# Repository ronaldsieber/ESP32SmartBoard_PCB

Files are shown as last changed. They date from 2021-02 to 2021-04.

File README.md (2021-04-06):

# ESP32SmartBoard_PCB
**KiCad project of a Printed Cuircit Board (PCB) for ESP32 with Temperature/Humidity/CO2 Sensors, User LEDs and Buttons.**

In the past I've implemented various Smart Projects with the ESP32 on break-out boards. On the one hand, break-out boards are very useful because they make hardware modifications as easy as software changes. On the other hand, it is very cumbersome to build several copies of the same circuit with break-out boards. Furthermore, they are mechanically fragile and not really particularly visually appealing. Therefore they are not very suitable for permanent use in the visible area of living rooms.

For this reason I designed the **ESP32SmartBoard_PCB**, which combines different projects on a single, professionally producible PCB. This allows now for reproducing multiple copies of a device without great effort and hide them in a small housing if necessary.

## Board Features

The *ESP32SmartBoard_PCB* contains the following components:
- ESP32 Development Kit
- DHT22 (combined temperature and humidity sensor)
- MH-Z19 (CO2 sensor with integrated temperature sensor)
- 9 freely usable user LEDs (LED0..LED8, arranged in one row and usable as a LED Bar)
- 3 freely usable user Buttons (KEY0, KEY1, BLE_CFG)

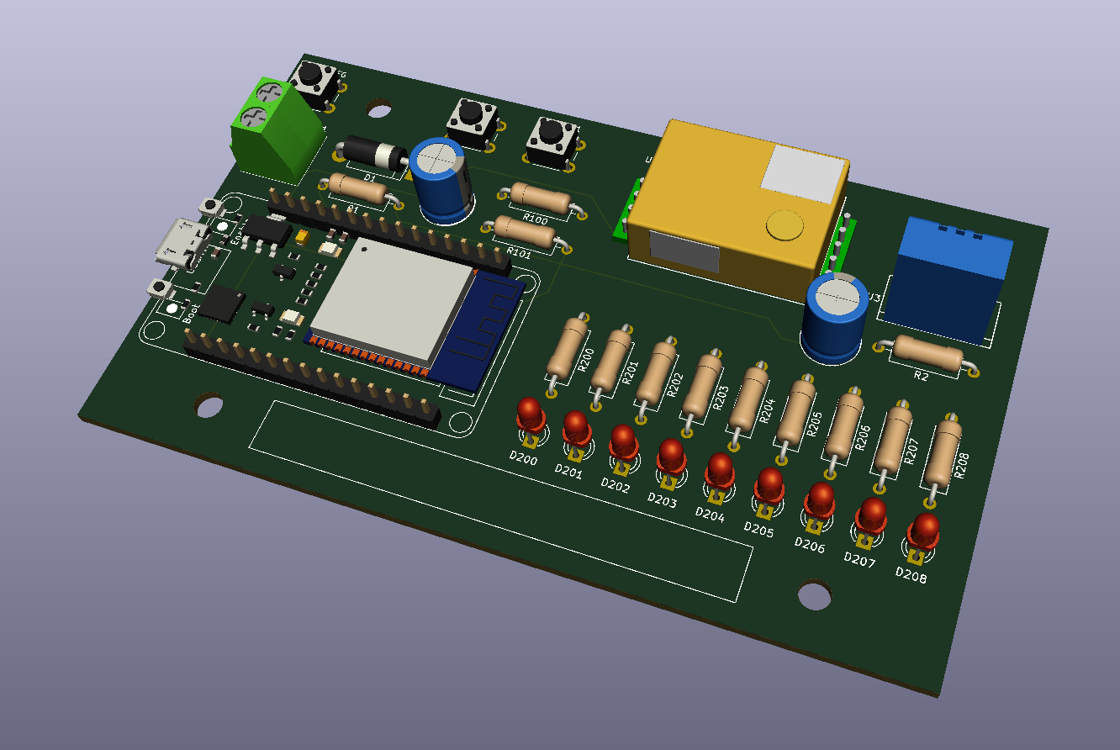
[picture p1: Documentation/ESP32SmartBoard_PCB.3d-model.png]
\[kicad_3d_model\]


## Board Description

The *ESP32SmartBoard_PCB* is a two-layer Printed Circuit Board (PCB), assembled on one side and only uses THT components (Through Hole Technology) that are very easy to solder. It can therefore be used very easily also by students and hobbyists.

The values of all components are specified in the [Schematic](Documentation/ESP32SmartBoard_PCB.sch.pdf).

The PCB size and the positions of the mounting holes allow installation in the plastic universal housing of 135 x 95 x 45 mm (article number 523117). This polystyrene housing (EPS) can be easily processed mechanically (e.g. cut out a viewing window for the LED Bar). It is available from various providers on the Internet.

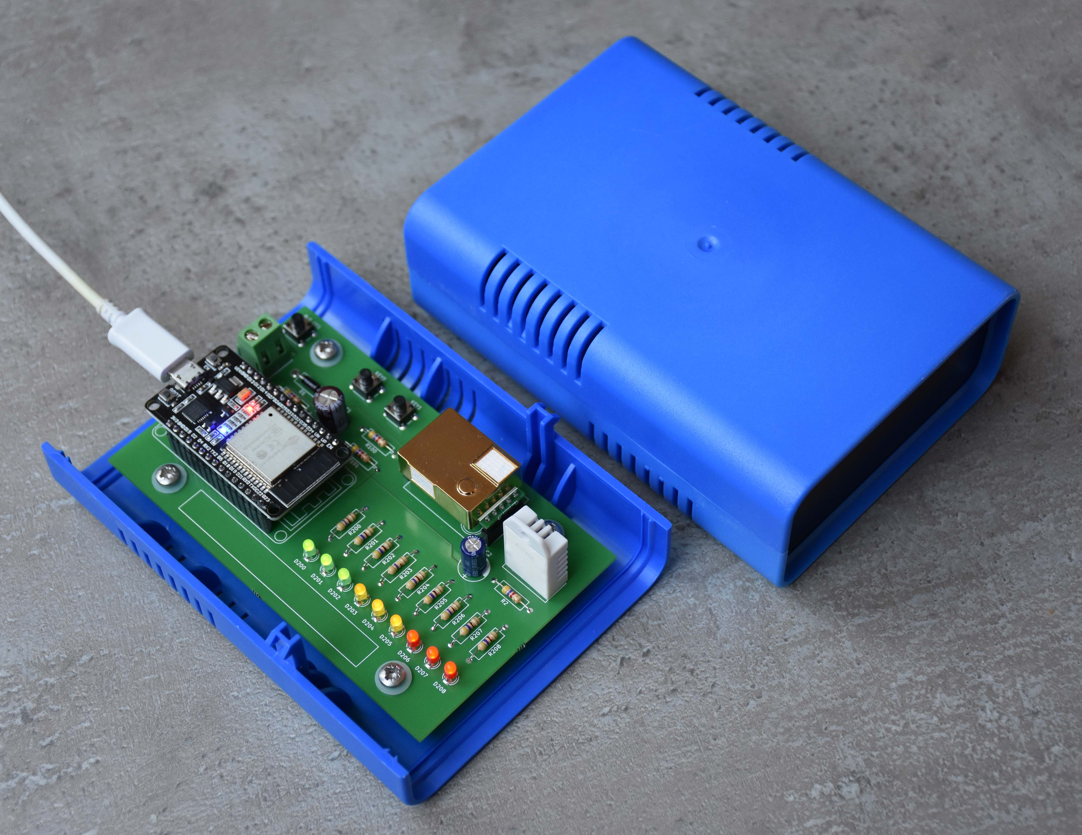
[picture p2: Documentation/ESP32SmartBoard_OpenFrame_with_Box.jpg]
\[ESP32SmartBoard_OpenFrame_with_Box\]


By searching in the Internet, several PCB manufacturers can be found who are able to directly import the KiCad layout file [ESP32SmartBoard_PCB.kicad_pcb](ESP32SmartBoard_PCB/ESP32SmartBoard_PCB.kicad_pcb). The PCBs with silkscreen (assembly printing) on the top are then sent by post after a few days.

## Power Supply

There are following options for the power supply of the board:
- Via USB connection of the ESP32 Development Kit (in this case Pin15/Vin of the ESP32DevKit acts as an output and supplies the rest of the circuit)
- Supply of 5 ... 6VDC to connector J1 (in this case the rest of the board supplies the ESP32DevKit and Pin15/Vin acts as an input)

## Commissioning

With the Arduino sketch from the [ESP32SmartBoard_IoCheck](https://github.com/ronaldsieber/ESP32SmartBoard_IoCheck) repository, all components of the board can be checked for correct function after assembly. The sketch is also a good starting point for new software projects based on this board.

## Schematic Symbols, Footprints and 3D Models

Not all schematic symbols, footprints and 3D models required for *ESP32SmartBoard_PCB* are contained in the native installed KiCad library. [External_KiCad_Parts.txt](Documentation/External_KiCad_Parts.txt) lists the additional components and their download links.

## Practice Notes

- The user LEDs are arranged in one row and can be used as a LED Bar. The colors of the LEDs should be selected according to the respective application. For example, to show the CO2 level in the form of a scale, the following grouping is suitable:
  * LED0..LED2: green = excellent
  * LED3..LED5: yellow = acceptable
  * LED6..LED8: red = critical

- It seems that there are several versions of the ESP32 Development Kit and the MH-Z19 CO2 sensor with pins of different widths. In my components, the diameter of the connection pins are larger than the diameter of the soldering pads in the footprint. This prevented me from soldering the components directly onto the board. However, I was able to solve the problem by using Pin Headers (see image above). The solder connections of the Pin Headers are small enough for the solder pads and the ESP32 Development Kit and MH-Z19 CO2 sensor can be easily plugged in.

## Software Projects for the ESP32SmartBoard

 - [ESP32SmartBoard_IoCheck](https://github.com/ronaldsieber/ESP32SmartBoard_IoCheck) - Checking of all components during commissioning and starting point for new software projects based on this board.
   
 - [ESP32SmartBoard_HttpSensors](https://github.com/ronaldsieber/ESP32SmartBoard_HttpSensors) - Embedded WebServer based Arduino Sketch for ESP32SmartBoard
   
 - [ESP32SmartBoard_MqttSensors](https://github.com/ronaldsieber/ESP32SmartBoard_MqttSensors) - MQTT Client based Arduino Sketch for ESP32SmartBoard

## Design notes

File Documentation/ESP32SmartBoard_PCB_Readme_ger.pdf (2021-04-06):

## ESP32SmartBoard_PCB

KiCad Projekt eines Printed Cuircit Boards (PCB) für ESP32 mit Temperatur-, Luftfeuchtigkeits- und CO2-Sensor, User LEDs und Bottons.

In der Vergangenheit habe ich verschiedene Smart Projects mit dem ESP32 auf Break-out Boards realisiert. Auf der einen Seite sind Break-out Boards sehr nützlich, da sie Hardware Modifikationen genauso einfach machen wie Software Änderungen. Auf der anderen Seite ist es aber sehr umständlich, mehrere Exemplare derselben Schaltung mit Break-out Boards aufzubauen. Außerdem sind diese mechanisch fragil und optisch nicht besonders ansprechend. Deswegen sind sie für eine Dauereinsatz im Sichtbereich von Wohnräumen nicht besonders geeignet.

Aus diesem Grund habe ich das ESP32SmartBoard_PCB designet, mit dem sich verschiedene Projekte auf einer einzigen, professionell produzierbaren PCB zusammenfassen lassen. Damit kann ich nun mehrfache Exemplare eines Gerätes ohne großen Aufwand reproduzieren und bei Bedarf in einem kleinen Gehäuse verstecken.

Board Features

Das ESP32SmartBoard_PCB beinhalte folgende Komponenten:
- ESP32 Development Kit
- DHT22 (kombinierter Temperatur- und Luftfeuchte-Sensor)
- MH-Z19 (CO2 Sensor mit integriertem Temperatur Sensor)
- 9 frei verwendbare User LEDs (LED0..LED8, in einer Reihe angeordnet und als Led Bar nutzbar)
- 3 frei verwendbare User Buttons (KEY0, KEY1, BLE_CFG)

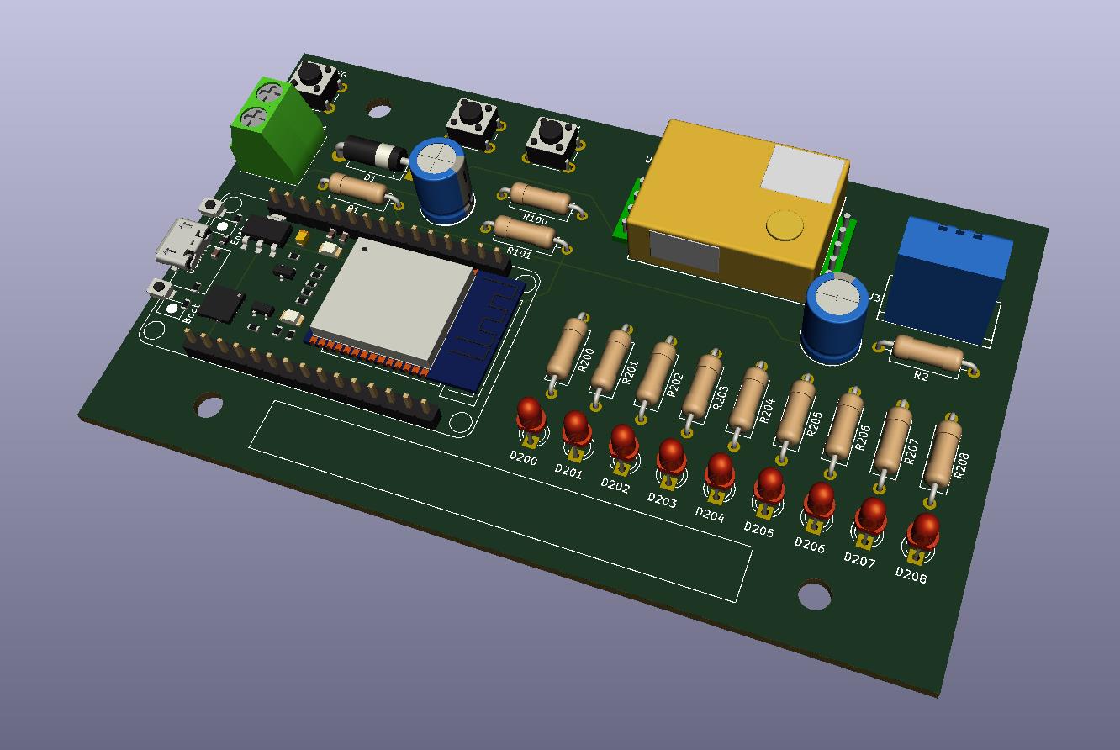
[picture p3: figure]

[kicad_3d_model]

Board Beschreibung

Das ESP32SmartBoard_PCB ist eine zweilagige Leiterplatte, einseitig bestückt und verwendet nur sehr einfach zu lötende THT Bauteile (Through Hole Technology). Es kann somit sehr leicht auch von Schülern und Bastlern genutzt werden.

Die Werte aller Bauteile sind im <Schaltplan> spezifiziert.

Die PCB Größe und die Positionen der Mounting Holes erlauben den Einbau in das Kunststoff Universal Gehäuse von 135 x 95 x 45 mm (Artikel Nummer 523117). Das Polystyrol Gehäuse (EPS) lässt sich leicht mechanisch bearbeiten (z.B. Sichtfenster für LED Bar ausschneiden). Es ist im Internet bei verschiedenen Anbietern erhältlich.

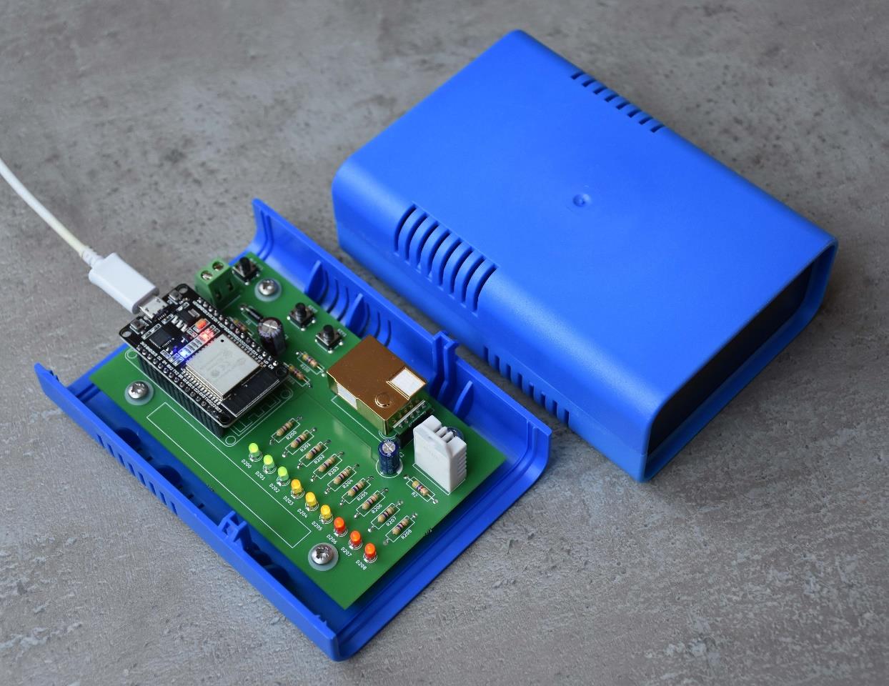
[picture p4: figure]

[esp32smartboard_pcb_photo]

Bei einer Suche im Internet findet man leicht mehrere PCB Hersteller, die direkt das KiCad Layout File ESP32SmartBoard_PCB.kicad_pcb importieren können. Die PCBs erhält man dann mit Bestückungsdruck auf der Oberseite nach wenigen Tagen per Post zugeschickt.

Spannungsversorgung

Für die Spannungsversorgung des Boards gibt es folgende Möglichkeiten:
- über den USB-Anschluss des ESP32 Development Kit (in diesem Fall wirkt Pin15/Vin des ESP32DevKit als Ausgang und versorgt die restliche Schaltung mit)
- Einspeisung von 5…6VDC an Konnektor J1 (in diesem Fall versorgt das Board das ESP32DevKit und Pin15/Vin wirkt als Eingang)

Inbetriebnahme

Mit dem Arduino Sketch des Repositories <ESP32SmartBoard_IoCheck> können alle Komponenten des Boards nach dem Bestücken auf ihre korrekte Funktion überprüft werden. Außerdem ist der Sketch eine gute Ausgangsbasis für neue Software Projekte basierend auf diesem Board.

Schaltplan Symbole, Footprints und 3D-Modelle

Nicht alle für das ESP32SmartBoard_PCB notwendigen Schaltplan Symbole, Footprints und 3D-Modelle sind in der nativ installierten KiCad Library enthalten. <External_KiCad_Parts.txt> listet die zusätzlichen Komponenten sowie deren Downlaod Links auf.

Praxis Hinweise

Die User LEDs sind in einer Reihe angeordnet und als Led Bar nutzbar. Die Farben der LEDs sollten entsprechend der jeweiligen Anwendung gewählt werden. Um beispielsweise den CO2 Level in Form einer Skala darzustellen, bietet sich die folgende Gruppierung an:
LED0-LED2: Grün = exzellent
LED3-LED5: Gelb = akzeptabel
LED6-LED8: Rot = kritisch

Es scheint, dass es vom ESP32 Development Kit sowie vom MH-Z19 CO2 Sensor verschiedene Varianten mit unterschiedlich breiten Pins gibt. Bei meinen Bauteilen sind die Durchmesser der Anschluss Pins größer als die Durchmesser der Löt-Pads im Footprint. Dadurch konnte ich die Bauteile nicht direkt auf die Platine löten. Ich konnte das Problem durch Verwendung von Pin-Headern lösen (siehe Image oben). Die Lötanschlüsse der Pin-Header sind schmal genug für die Löt-Pads und ESP32 Development Kit und MH-Z19 CO2 Sensor lassen sich leicht einstecken.

Software Projekte für das ESP32SmartBoard

- <ESP32SmartBoard_IoCheck> – Prüfen aller Komponenten während der Inbetriebnahme und Ausgangsbasis für neue Software Projekte basierend auf diesem Board
- <ESP32SmartBoard_HttpSensors> – Embedded WebServer basierter Arduino Sketch für das ESP32SmartBoard
- <ESP32SmartBoard_MqttSensors> – MQTT Client basierter Arduino Sketch für das ESP32SmartBoard

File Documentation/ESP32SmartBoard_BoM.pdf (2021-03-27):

Component | Description | Part | References | Value | Footprint | Quantity | Order Number on www.reichelt.de
1 | Polarized capacitor | CP | C2 | 47 µF | CP_Radial_D8.0mm_P3.50mm | 1 | RND 150ENR AO
2 | Polarized capacitor | CP | C1 | 100 µF | CP_Radial_D8.0mm_P3.50mm | 1 | RAD 100/35
3 | Diode | D | D1 | 1N4001 | D_5W_P12.70mm_Horizontal | 1 | 1N 4001
4 | Light emitting diode | LED | D200 D201 D202 | LED green | LED_D3.0mm | 3 | LED 3MM 2MA GN
5 | Light emitting diode | LED | D203 D204 D205 | LED yellow | LED_D3.0mm | 3 | LED 3MM 2MA GE
6 | Light emitting diode | LED | D206 D207 D208 | LED red | LED_D3.0mm | 3 | LED 3MM 2MA RT
7 | Screw Terminal | Screw_Terminal_01x02 | J1 | TermBlock | TerminalBlock_Phoenix_MKDS1.5-2pol | 1 | LAKL 1,5 2 5,08
8 | Resistor | R | R200 R201 R202 R203 R204 R205 R206 R207 R208 | 470R | R_Axial_DIN0309_L9.0mm_D3.2mm_P12.70mm_Horizontal | 9 | 1/4W 470
9 | Resistor | R | R1 R2 R100 R101 | 4k7 | R_Axial_DIN0309_L9.0mm_D3.2mm_P12.70mm_Horizontal | 4 | 1/4W 4,7K
10 | Push button | SW_Push | SW1 SW100 SW101 | KEY | SW_PUSH_6mm_h5mm | 3 | TASTER 9303
11 | DHT22 temperature and humidity sensor | DHT22_Temperature_Humidity | U3 | DHT22 | DHT22_Temperature_Humidity | 1 | DEBO DHT 22
12 | ESP32_DevKit | ESP32_DevKit_V1_DOIT | U1 | ESP32_DevKit | esp32_devkit_v1_doit | 1 | DEBO JT ESP32
13 | NDIR Carbon dioxide Module, CO2 | MH-Z19B | U2 | MH-Z19B | Winsen_MH-Z19B | 1 | CO2 MH-Z19C-PH
(optional) | Pin Headers | Optional for ESP32_DevKit | Pin header 2.54mm, 1x20, separable, tin-plated | | Hint: shorten manually to 15 pins | 2 | FIS BL1 20 Z
(optional) | Pin Headers | Optional for MH-Z19B | Pin header 2.54mm, 1x5 | | | 1 | BKL 10120947
(optional) | Pin Headers | Optional for MH-Z19B | Pin header 2.54mm, 1x4 | | | 1 | BKL 10120946
(optional) | Housing Box | Housing Box | Small case, 135 x 95 x 45 mm | | | 1 | EUROBOX BL
(optional) | Mounting Screws | Mounting Screws | Self-tapping screws, PZD, 3.5 x 9.5 mm | | | 4 | SBL-E 35095-100

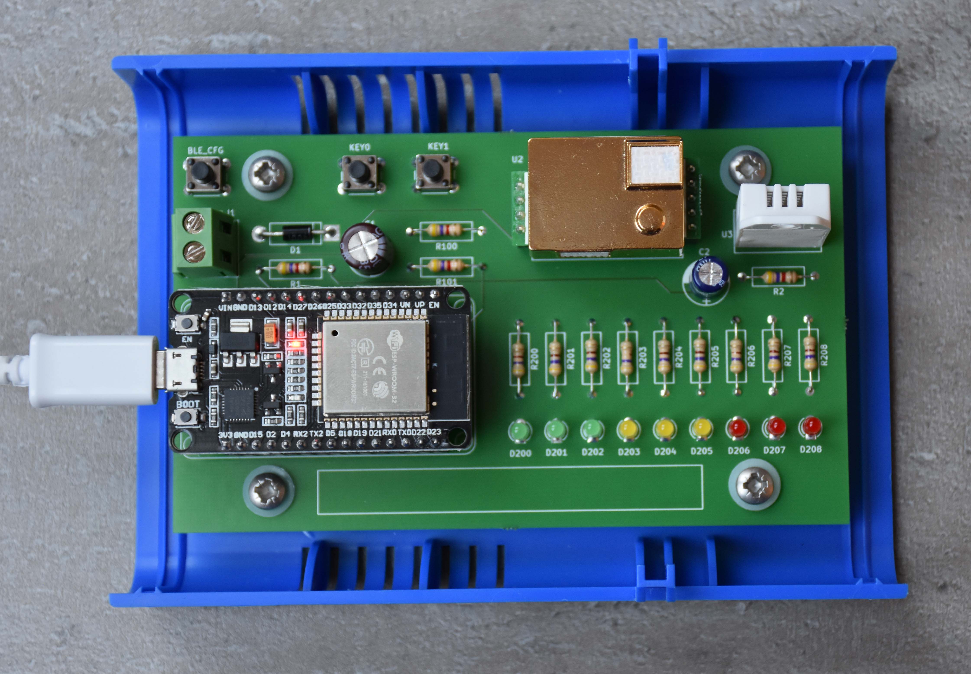
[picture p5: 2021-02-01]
Documentation/ESP32SmartBoard_OpenFrame.jpg

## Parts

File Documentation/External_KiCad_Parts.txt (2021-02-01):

Part:   ESP32_DevKit_V1_DOIT
            Symbol / Footprint / 3D-Model:          https://gitlab.com/VictorLamoine/kicad

Part:   MH-Z19B
            Symbol / Footprint:                     https://gitlab.com/IT-Berater/twco2sensor-mh-z19b
            3D-Model:                               https://github.com/ronaldsieber/MH-Z19_3D_Model

Part:   DHT22
            Symbol / Footprint:                     https://github.com/skorokithakis/kicad-lib/blob/master/Sensors.pretty/DHT22_Temperature_Humidity.kicad_mod
            3D-Model:                               [KiCad DHT11 3D Model]

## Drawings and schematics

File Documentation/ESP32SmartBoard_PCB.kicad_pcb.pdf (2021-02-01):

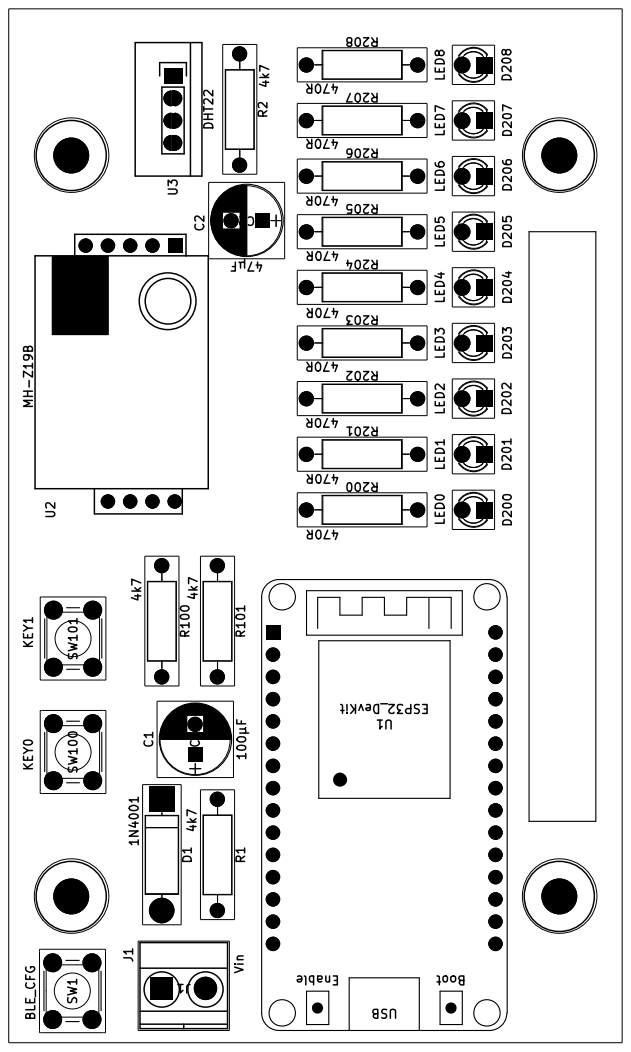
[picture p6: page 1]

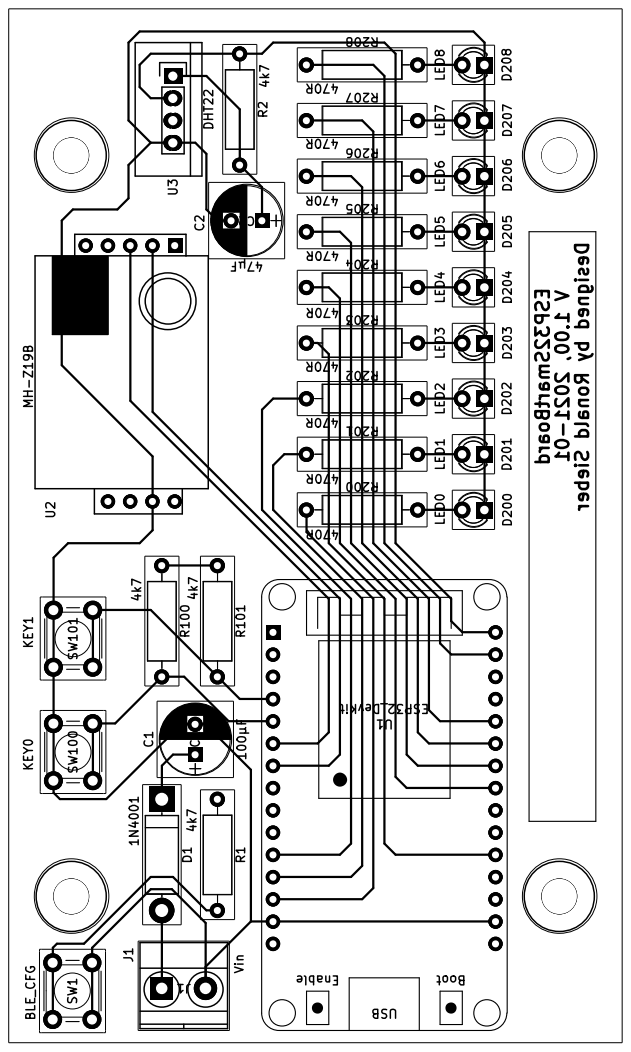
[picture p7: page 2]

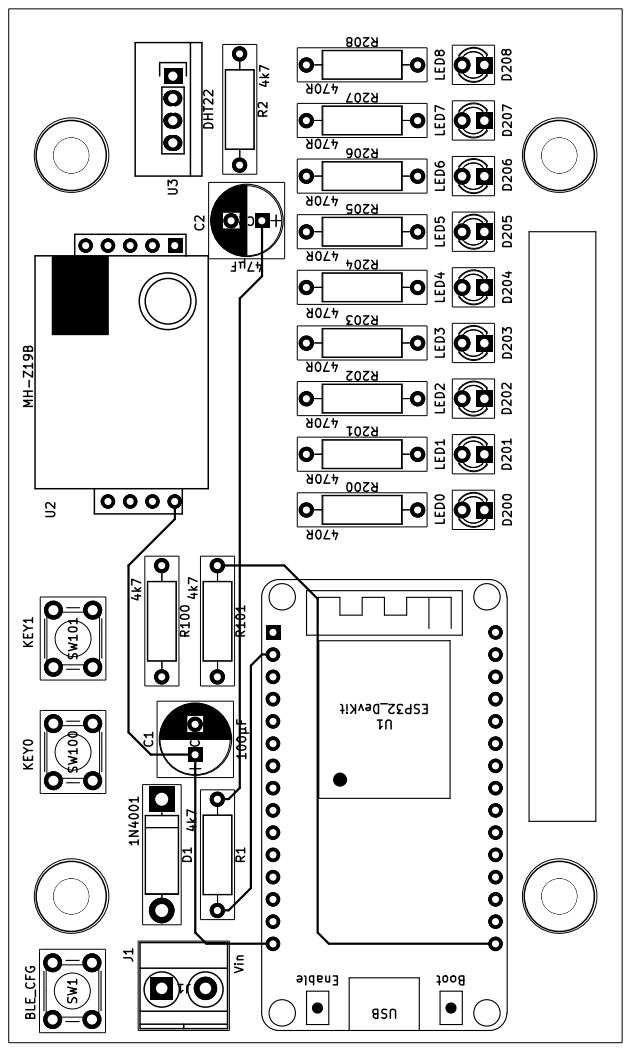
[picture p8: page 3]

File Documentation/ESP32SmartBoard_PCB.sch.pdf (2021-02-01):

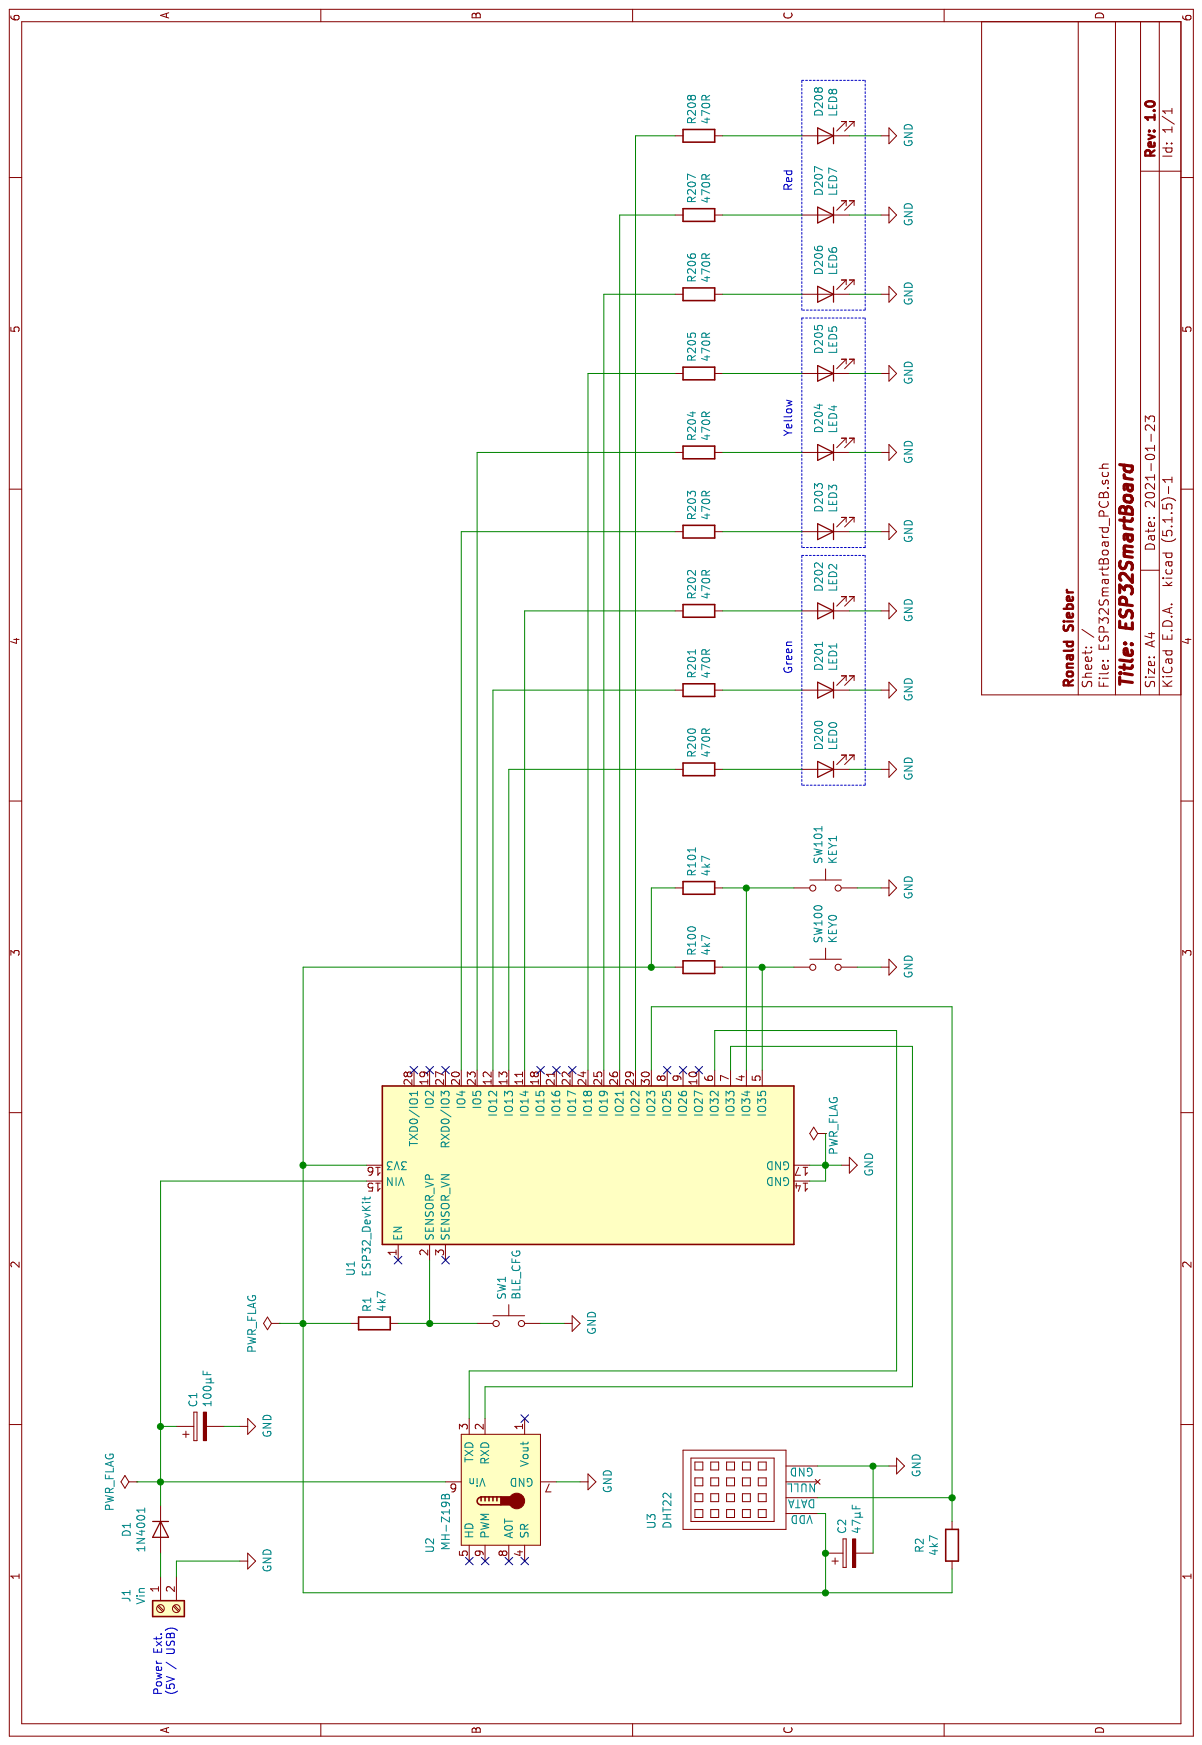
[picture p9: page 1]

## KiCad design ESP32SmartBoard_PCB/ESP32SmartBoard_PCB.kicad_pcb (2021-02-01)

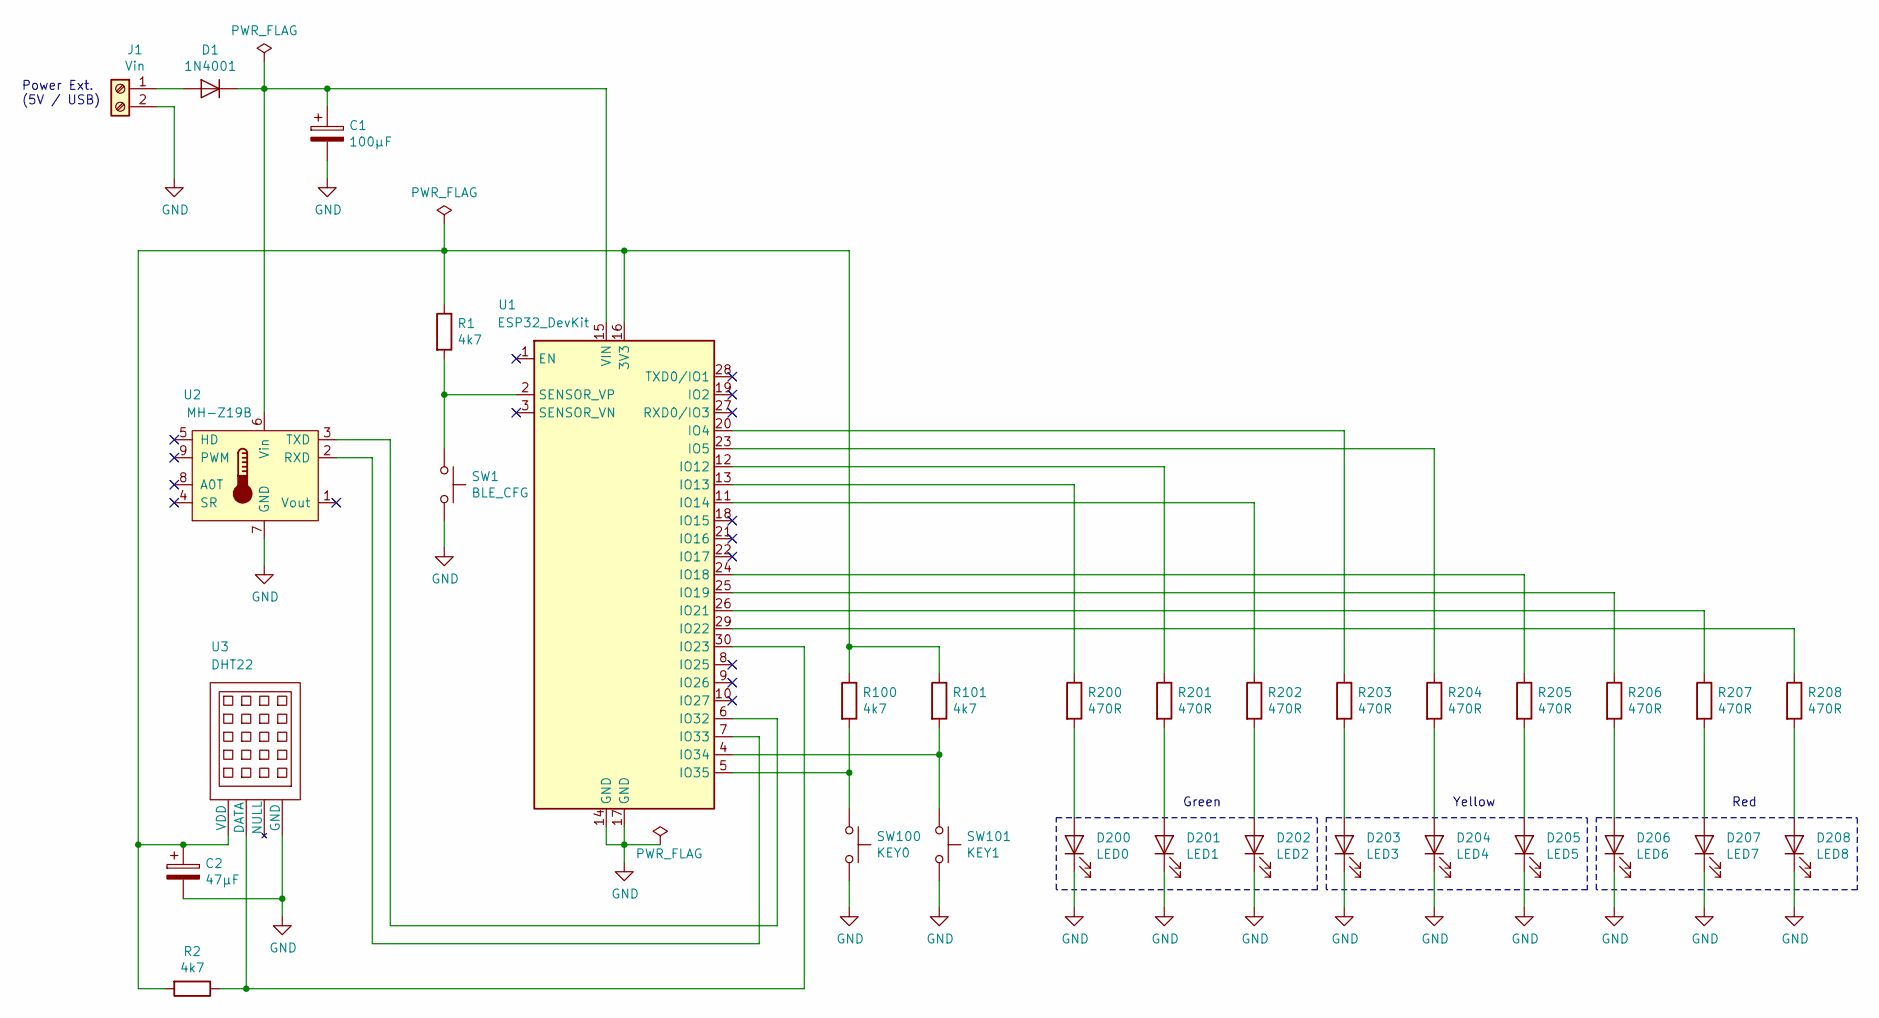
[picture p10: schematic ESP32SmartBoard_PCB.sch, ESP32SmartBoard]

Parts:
C1: 100µF; CP_Radial_D8.0mm_P3.50mm
C2: 47µF; CP_Radial_D8.0mm_P3.50mm
D1: 1N4001; D_5W_P12.70mm_Horizontal
D200: LED0; LED_D3.0mm
D201: LED1; LED_D3.0mm
D202: LED2; LED_D3.0mm
D203: LED3; LED_D3.0mm
D204: LED4; LED_D3.0mm
D205: LED5; LED_D3.0mm
D206: LED6; LED_D3.0mm
D207: LED7; LED_D3.0mm
D208: LED8; LED_D3.0mm
J1: Vin; TerminalBlock_Phoenix_MKDS1.5-2pol
R1, R2, R100, R101: 4k7; R_Axial_DIN0309_L9.0mm_D3.2mm_P12.70mm_Horizontal
R200, R201, R202, R203, R204, R205, R206, R207, R208: 470R; R_Axial_DIN0309_L9.0mm_D3.2mm_P12.70mm_Horizontal
SW1: BLE_CFG; SW_PUSH_6mm_h5mm
SW100: KEY0; SW_PUSH_6mm_h5mm
SW101: KEY1; SW_PUSH_6mm_h5mm
U1: ESP32_DevKit; esp32_devkit_v1_doit
U2: MH-Z19B; Winsen_MH-Z19B
U3: DHT22; DHT22_Temperature_Humidity

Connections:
GND: C1.2, C2.2, D200.1 (K), D201.1 (K), D202.1 (K), D203.1 (K), D204.1 (K), D205.1 (K), D206.1 (K), D207.1 (K), D208.1 (K), J1.2, SW1.2, SW100.2, SW101.2, U1.14 (GND), U1.17 (GND), U2.7 (GND), U3.4 (GND)
unnamed: C1.1, D1.1 (K), U1.15 (VIN), U2.6 (Vin)
unnamed: C2.1, R1.1, R2.2, R100.1, R101.1, U1.16 (3V3), U3.1 (VDD)
unnamed: D1.2 (A), J1.1
unnamed: D200.2 (A), R200.2
unnamed: D201.2 (A), R201.2
unnamed: D202.2 (A), R202.2
unnamed: D203.2 (A), R203.2
unnamed: D204.2 (A), R204.2
unnamed: D205.2 (A), R205.2
unnamed: D206.2 (A), R206.2
unnamed: D207.2 (A), R207.2
unnamed: D208.2 (A), R208.2
unnamed: R1.2, SW1.1, U1.2 (SENSOR_VP)
unnamed: R2.1, U1.30 (IO23), U3.2 (DATA)
unnamed: R100.2, SW100.1, U1.5 (IO35)
unnamed: R101.2, SW101.1, U1.4 (IO34)
unnamed: R200.1, U1.13 (IO13)
unnamed: R201.1, U1.12 (IO12)
unnamed: R202.1, U1.11 (IO14)
unnamed: R203.1, U1.20 (IO4)
unnamed: R204.1, U1.23 (IO5)
unnamed: R205.1, U1.24 (IO18)
unnamed: R206.1, U1.25 (IO19)
unnamed: R207.1, U1.26 (IO21)
unnamed: R208.1, U1.29 (IO22)
unnamed: U1.6 (IO32), U2.3 (TXD)
unnamed: U1.7 (IO33), U2.2 (RXD)

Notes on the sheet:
Power Ext. (5V / USB)
Green
Yellow
Red

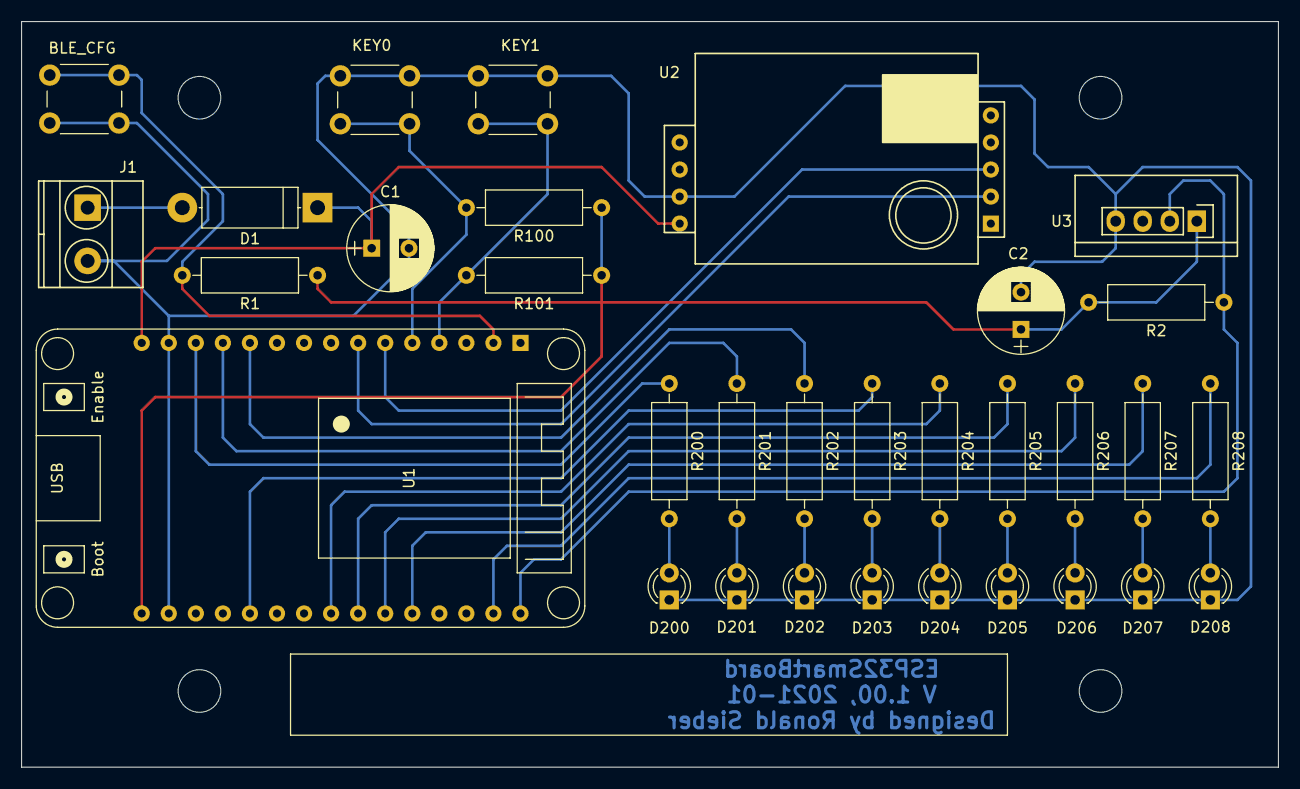
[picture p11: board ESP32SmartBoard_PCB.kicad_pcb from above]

Board: 2 copper layers, 118.0 x 70.0 mm, 32 parts (0 on the bottom side), 28 nets.

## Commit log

2021-02-01 Add files via upload
    Initial Version
    [ESP32SmartBoard_PCB.kicad_pcb, ESP32SmartBoard_PCB.sch]
2021-04-06 Update README.md
    Related software projects for the ESP32SmartBoard added
